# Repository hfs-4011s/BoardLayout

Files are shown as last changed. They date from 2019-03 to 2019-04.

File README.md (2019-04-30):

HFS 4011s PCB Design Files
=====
# Development Guide
### Software
PCB design software (EAGLE) can be downloaded [here](https://www.autodesk.com/education/free-software/eagle).

Tutorials:

[Schematic design tutorial](https://learn.sparkfun.com/tutorials/using-eagle-schematic/all)

[Creating device footprints](https://learn.sparkfun.com/tutorials/designing-pcbs-smd-footprints)

[Advanced layout](https://learn.sparkfun.com/tutorials/designing-pcbs-advanced-smd)

### Useful links
The ESP32 and USB design follows the same format as the
[HUZZAH32 ESP32 Feather](https://github.com/adafruit/Adafruit-HUZZAH32-ESP32-Feather-PCB),
so check out their [documentation](https://learn.adafruit.com/adafruit-huzzah32-esp32-feather/overview)
for programming the board using the Arduino IDE.

The battery charge design follows the same format as the [PowerBoost 500](https://github.com/adafruit/Adafruit-PowerBoost-500-Charger-PCB).
An overview can be found [here](https://learn.adafruit.com/adafruit-powerboost-500-plus-charger/overview).

# Usage
This board is meant to interface with an FPAA board developed at the Georgia
Institute of Technology and serves as part of an overall noise cancellation
pipeline meant to showcase the versatility of this technology. Our board handles
sending music and measured noise over to the FPAA, and the FPAA incorporates
our noise cancellation algorithm and sends its output to connected speakers.

This board, denoted as the HFS-4011s mainboard, includes circuitry for regulating
the battery supply voltage to 5V and 3.3V, handles charging the battery from a
micro-USB connector, and handles programming the onboard ESP32 via micro-USB.

The ESP32 is set up to connect to buttons for controlling the ANC state. A 5V
logic level SPI interface is set up and is meant to interface with LEDs to show
headphone status. The mainboard also contains a 16-bit DAC for converting the
received music to an analog signal to send over to an FPAA or speakers.

There are also a few onboard LEDs for debugging and status verification.

* `LED1` is green if the battery is fully charged
* `LED2` is orange if the battery is currently charging
* `PWR` is a power indicator LED and is blue if 5V is output from the regulator
* `LBO` is a battery status indicator LED and is red if the battery is discharged
* `D2` is a red LED connected to `GPIO13` meant for debugging

Even with solder paste, this board can be hard to assemble by hand. We ran into
a lot of problems regarding unintended shorts from the reflow process. If removing
the USB-UART bridge is necessary, the ESP32 can be programmed normally through
pins 34 and 35 (`u0RXD` and `u0TXD` respectively), but when you get to the
`Connecting...` stage, make sure the following protocol is followed:

* Short `GPIO2` and `GPIO0` to ground.
* Press the RESET button (`SW1`), which is connected to the ESP32 `EN` pin, to
momentarily reset the microcontroller. Pressing `SW1` shorts the `EN` pin to ground,
so this can be done manually as well.

After a couple of moments, the ESP32 should be flashed. The RESET button needs
to be pressed again to cycle the ESP32, and the flashed program should now run.

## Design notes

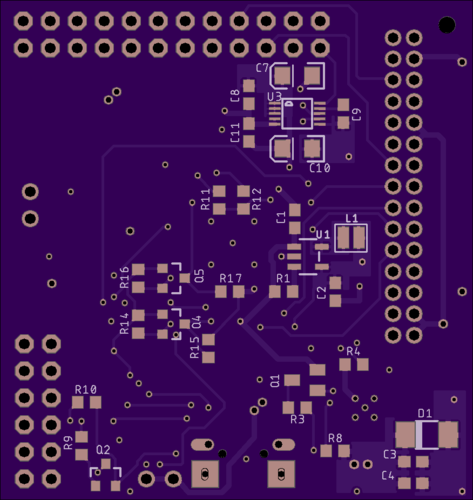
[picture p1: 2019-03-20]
HFS_4011s_Rev_0/osh_images/board_bottom.png

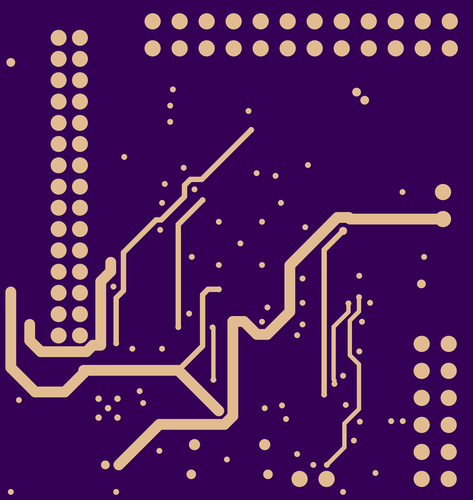
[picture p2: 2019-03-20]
HFS_4011s_Rev_0/osh_images/internal_signal_plane.png

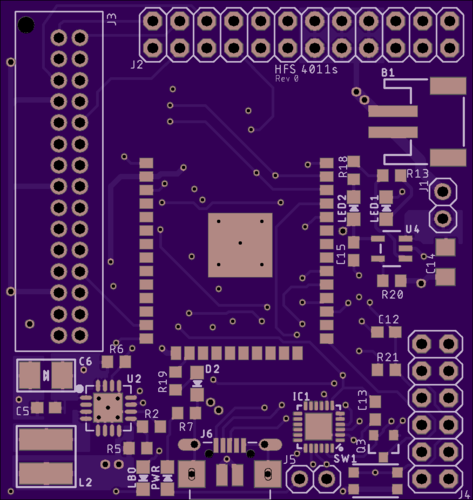
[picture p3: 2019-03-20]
HFS_4011s_Rev_0/osh_images/board_top.png

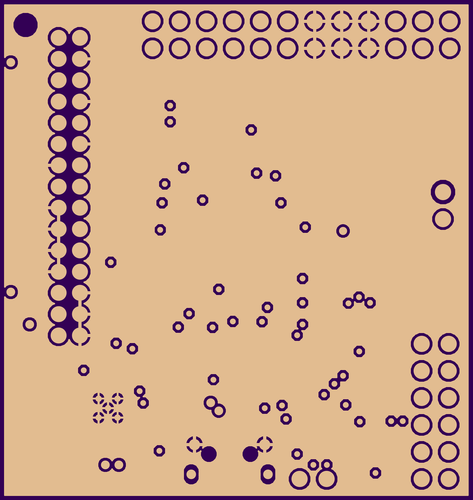
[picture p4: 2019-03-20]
HFS_4011s_Rev_0/osh_images/internal_ground_plane.png

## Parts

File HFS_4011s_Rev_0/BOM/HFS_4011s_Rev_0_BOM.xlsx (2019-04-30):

Official Number | Part | Value | Device | Package | Description | Quantity | Price 1 | Manufacturer_ID | Supplier_ID | Link 1 | Alternate ID | Alternate Link
1 | B1 | 3.7 V 6.6 Ah battery | BATTERY | JSTPH2 | CR1220 SMT - Digikey: 3001K-ND | 1 | 29.5 | 353 | 1528-1835-ND | https://www.digikey.com/product-detail/en/adafruit-industries-llc/353/1528-1835-ND/5054549 | 353 | https://www.adafruit.com/product/353
2 | C1, C3, C13, C15 | 10uF | C-EUC0603 | C0603 | CAPACITOR, European symbol | 4 | 0.21 | GRM188R61A106KE69D |  | https://www.digikey.com/product-detail/en/murata-electronics-north-america/GRM188R61A106KE69D/490-10474-1-ND/5026392 | JMK107BJ106MA-T | https://www.digikey.com/product-detail/en/taiyo-yuden/JMK107BJ106MA-T/587-1256-1-ND/931033
3 | C12 | 1uF | C-EUC0603 | C0603 | CAPACITOR, European symbol | 1 | 0.1 | CL10A105KP8NNNC |  | https://www.digikey.com/product-detail/en/samsung-electro-mechanics/CL10A105KP8NNNC/1276-1182-1-ND/3889268 | CL10A105KQ8NNNC | https://www.digikey.com/product-detail/en/samsung-electro-mechanics/CL10A105KQ8NNNC/1276-1036-1-ND/3889122
4 | C14 | 4.7uF | C-USC1206 | C1206 | CAPACITOR, American symbol | 1 | 0.26 | CL31B475KAHNNWE |  | https://www.digikey.com/product-detail/en/samsung-electro-mechanics/CL31B475KAHNNWE/1276-3178-1-ND/3891264 | CL31A475KOHNNNE | https://www.digikey.com/product-detail/en/samsung-electro-mechanics/CL31A475KOHNNNE/1276-3059-1-ND/3891145
5 | C2 | 22uF | C-EUC0603 | C0603 | CAPACITOR, European symbol | 1 | 0.31 | GRM188R61A226ME15D |  | https://www.digikey.com/product-detail/en/murata-electronics-north-america/GRM188R61A226ME15D/490-10476-1-ND/5026394 | CL10A226MQ8NRNE | https://www.digikey.com/product-detail/en/samsung-electro-mechanics/CL10A226MQ8NRNE/1276-2868-1-ND/3890954
6 | C4, C8, C11 | 0.1uF | C-EUC0603 | C0603 | CAPACITOR, European symbol | 3 | 0.1 | CL10B104KB8NNNC |  | https://www.digikey.com/product-detail/en/samsung-electro-mechanics/CL10B104KB8NNNC/1276-1000-1-ND/3889086 | CL10B104KO8NNNC | https://www.digikey.com/product-detail/en/samsung-electro-mechanics/CL10B104KO8NNNC/1276-1005-1-ND/3889091
7 | C5 | 2.2uF | C-EUC0603 | C0603 | CAPACITOR, European symbol | 1 | 0.11 | CL10A225KP8NNNC |  | https://www.digikey.com/product-detail/en/samsung-electro-mechanics/CL10A225KP8NNNC/1276-1085-1-ND/3889171 | CL10A225KQ8NNNC | https://www.digikey.com/product-detail/en/samsung-electro-mechanics/CL10A225KQ8NNNC/1276-1183-1-ND/3889269
8 | C6 | 100uF/6V | CAP_TANTALUMB/3528_REFLOW | EIA3528-21/B-R | Tantalum Capacitors | 1 | 0.65 | TPSB107K006R0250 |  | https://www.digikey.com/product-detail/en/avx-corporation/TPSB107K006R0250/478-3080-6-ND/1642660 | TPSB107M006R0250 | https://www.digikey.com/product-detail/en/avx-corporation/TPSB107M006R0250/478-4978-6-ND/1888274
9 | C7, C10 | 10uF | 10UF-TANT | EIA3216 | 10uF Tantalum SMT | 2 | 0.41 | TPSA106K010R0900 |  | https://www.digikey.com/product-detail/en/avx-corporation/TPSA106K010R0900/478-1751-1-ND/564783 | TPSA106M010R0900 | https://www.digikey.com/product-detail/en/avx-corporation/TPSA106M010R0900/478-9034-1-ND/4561900
10 | C9 | 10nF | C-EUC0603 | C0603 | CAPACITOR, European symbol | 1 | 0.1 | CL10B103KB8NNNC |  | https://www.digikey.com/product-detail/en/samsung-electro-mechanics/CL10B103KB8NNNC/1276-1009-1-ND/3889095 | CL10B103KB8NCNC | https://www.digikey.com/product-detail/en/samsung-electro-mechanics/CL10B103KB8NCNC/1276-1921-1-ND/3890007
11 | D1 | SMAJ5.0CALFDKR-ND | SMAJ5.0CALFDKR-ND | DO-214AC | TVS Diode | 1 | 0.47 | SMAJ5.0CA |  | https://www.digikey.com/product-detail/en/littelfuse-inc/SMAJ5.0CA/SMAJ5.0CALFCT-ND/762463 | SMAJ5.0CA | https://www.mouser.com/ProductDetail/Bourns/SMAJ50CA?qs=sGAEpiMZZMuGq%2Fv7cZsUqyrTMop0Zr6V
12 | D2, LBO | RED | LED0805_NOOUTLINE | CHIPLED_0805_NOOUTLINE | LED | 1 | 0.31 | LTST-C171KRKT |  | https://www.digikey.com/product-detail/en/lite-on-inc/LTST-C171KRKT/160-1427-1-ND/386800 | LTST-C170KRKT | https://www.digikey.com/product-detail/en/lite-on-inc/LTST-C170KRKT/160-1415-1-ND/386778
13 | IC1 | CP2104 | CP2104 | QFN24_4MM_SMSC | CP2104 - USB to UART Bridge | 1 | 1.65 | CP2104-F03-GMR |  | https://www.digikey.com/product-detail/en/silicon-labs/CP2104-F03-GMR/336-4146-1-ND/7650425 | CP2104-F03-GMR | https://www.mouser.com/ProductDetail/Silicon-Labs/CP2104-F03-GMR
42 | J1 | 1X02 | 1X02 | 1X02 | Power Switch and ANC Switch | 2 | 1.5 | EG1218 | COM-00102 | https://www.sparkfun.com/products/102 | EG1903-ND | https://www.digikey.com/product-detail/en/e-switch/EG1218/EG1903-ND/101726
40 | J2, J4, J5 | 2x23 Stacking Headers | 2x23 | 2x23 | 2 pack of 2x23 Stacking header pins | 1 | 4.95 | 706 |  | https://www.adafruit.com/product/706 | PRT-12790 | https://www.sparkfun.com/products/12790
14 |  |  | Molex_Socket_Contact |  | Socket contacts for iGrid connector (50 cost 7.18) Only really need to buy once/twice since we probably only need this for one/two boards | 10 | 0.192 | 5016471100 | WM13028-ND | https://www.digikey.com/product-detail/en/molex/5016471100/WM13028-ND/2818865 | 51R1306 | https://www.newark.com/molex/501647-1100/contact-socket-22awg-crimp/dp/51R1306?CMP=AFC-OP#
 |  |  |  |  | Molex iGrid mating connector | 1 | 2.37 | 501646-3000 |  | https://www.digikey.com/product-detail/en/molex/501646-3000/WM6068-ND/1787769 | 501646-3000 | https://www.mouser.com/ProductDetail/Molex/501646-3000
15 | J3 |  | MOLEX_IGRID_15X2CONNECTOR | MOLEX_IGRID15X2CONNECTOR |  | 1 | 2.54 | 501645-3020 |  | https://www.digikey.com/product-detail/en/molex/501645-3020/WM6082-ND/1787783 | 501645-3020 | https://www.mouser.com/ProductDetail/Molex/501645-3020?qs=AcmJtBVhzkToA%2FCFca6o%252BA%3D%3D
16 | J6 | microUSB | USBMICRO_20329 | 4UCONN_20329 | USB Connectors | 1 | 0.78 | 10103592-0001LF |  | https://www.digikey.com/product-detail/en/amphenol-icc-fci/10103592-0001LF/609-4048-1-ND/2350355 | 10103592-0001LF | https://www.mouser.com/ProductDetail/Amphenol-FCI/10103592-0001LF?qs=EnLMdcWnKABhRNh1n9QQyg%3D%3D
17 | L1 | 2.2uH/NRH2412T2R2MNGH | INDUCTORNRH2412T | INDUCTOR_TAIYOYUDEN_NRH2412T | Inductors | 1 | 0.23 | NRH2412T2R2MNGH | 587-3443-1-ND | https://www.digikey.com/product-detail/en/taiyo-yuden/NRH2412T2R2MNGH/587-3443-1-ND/4157783 | 55AC0812 | https://www.newark.com/taiyo-yuden/nrh2412t2r2mngh/inductor-wirewound-2-2uh-1a/dp/55AC0812?CMP=AFC-OP
18 | L2 | VLC5045-6.8uH | INDUCTORTDK_VLC5045 | INDUCTOR_5X5MM_TDK_VLC5045 | Inductors (schematic version is obsolete) | 1 | 0.48 | VLS5045EX-6R8M | 445-174855-1-ND | https://www.digikey.com/product-detail/en/tdk-corporation/VLS5045EX-6R8M/445-174855-1-ND/6560412 | 32AC9101 | https://www.newark.com/tdk/vls5045ex-6r8m/inductor-6-8uh-2-9a-20-wirewound/dp/32AC9101?CMP=AFC-OP
19 | LED1 | GREEN | LED0805_NOOUTLINE | CHIPLED_0805_NOOUTLINE | LED | 1 | 0.31 | LTST-C171KGKT |  | https://www.digikey.com/product-detail/en/lite-on-inc/LTST-C171KGKT/160-1426-1-ND/386798 | LTST-C171GKT | https://www.digikey.com/product-detail/en/lite-on-inc/LTST-C171GKT/160-1423-6-ND/1218382
20 | LED2 | ORANGE | LED0805_NOOUTLINE | CHIPLED_0805_NOOUTLINE | LED | 1 | 0.31 | LTST-C170KFKT |  | https://www.digikey.com/product-detail/en/lite-on-inc/LTST-C170KFKT/160-1413-1-ND/386774 | LTST-C171AKT | https://www.digikey.com/product-detail/en/lite-on-inc/LTST-C171AKT/160-1419-1-ND/386784
21 | PWR | BLUE | LED0805_NOOUTLINE | CHIPLED_0805_NOOUTLINE | LED | 1 | 0.51 | LTST-C171TBKT |  | https://www.digikey.com/product-detail/en/lite-on-inc/LTST-C171TBKT/160-1645-1-ND/573585 | LTST-C170TBKT | https://www.digikey.com/product-detail/en/lite-on-inc/LTST-C170TBKT/160-1579-1-ND/564889
22 | Q1 | MMUN2133LT1G | MUN2114T1-PNP_DRIVER-SC59-BEC | SC59-BEC | PNP Bias Resistor Transistor | 1 | 0.13 | MMUN2133LT1G |  | https://www.digikey.com/product-detail/en/on-semiconductor/MMUN2133LT1G/MMUN2133LT1GOSCT-ND/2705149 | MMUN2133LT1G | https://www.mouser.com/ProductDetail/ON-Semiconductor/MMUN2133LT1G
23 | Q2, Q3 | mmbt2222 | TRANSISTOR_NPNSOT23-3 | SOT23-3 | Transistor NPN | 2 | 0.13 | MMBT2222LT1G |  | https://www.digikey.com/product-detail/en/on-semiconductor/MMBT2222LT1G/MMBT2222LT1GOSCT-ND/1139808 | MMBT2222A-TP | https://www.digikey.com/product-detail/en/micro-commercial-co/MMBT2222A-TP/MMBT2222ATPMSCT-ND/717394
24 | Q4, Q5 | BSS138 | MOSFET-NCHANNELSMD | SOT23-3 | N-channel MOSFET | 2 | 0.31 | BSS138 |  | https://www.digikey.com/product-detail/en/on-semiconductor/BSS138/BSS138CT-ND/244294 | BSS138 | https://www.mouser.com/ProductDetail/ON-Semiconductor-Fairchild/BSS138
 | R1 | 100K | R-US_R0603 | R0603 | RESISTOR, American symbol | 1 | 0.11 | RR0816P-104-D |  | https://www.digikey.com/product-detail/en/susumu/RR0816P-104-D/RR08P100KDCT-ND/432772 | ERA-3AEB104V | https://www.digikey.com/product-detail/en/panasonic-electronic-components/ERA-3AEB104V/P100KDBCT-ND/1466100
 | R11, R12 | 5k | R-US_R0603 | R0603 | RESISTOR, American symbol (bought 4.99kohm resistors) | 2 | 0.35 | ERA-3AEB4991V |  | https://www.digikey.com/product-detail/en/panasonic-electronic-components/ERA-3AEB4991V/P4.99KDBCT-ND/3075985 | ERA-3AEB4991V | https://www.mouser.com/ProductDetail/Panasonic/ERA-3AEB4991V
25 | R14, R15, R16, R17 | 5.1k | R-US_R0603 | R0603 | RESISTOR, American symbol | 4 | 0.35 | ERA-3AEB512V |  | https://www.digikey.com/product-detail/en/panasonic-electronic-components/ERA-3AEB512V/P5.1KDBCT-ND/1466069 | RG1608N-512-W-T1 | https://www.digikey.com/product-detail/en/susumu/RG1608N-512-W-T1/RG16N5.1KWCT-ND/600802
26 | R18 | 470 | R-US_R0603 | R0603 | RESISTOR, American symbol | 1 | 0.1 | CRGCQ0603J470R |  | https://www.digikey.com/product-detail/en/te-connectivity-passive-product/CRGCQ0603J470R/A130089CT-ND/8577921 | ERJ-3EKF4700V | https://www.digikey.com/product-detail/en/panasonic-electronic-components/ERJ-3EKF4700V/P470HCT-ND/1746781
27 | R2, R8 | 340K | R-US_R0603 | R0603 | RESISTOR, American symbol | 2 | 0.8 | RN73C1J340KBTD |  | https://www.digikey.com/product-detail/en/te-connectivity-passive-product/RN73C1J340KBTD/A124740CT-ND/6557785 | RC0603FR-07340KL | https://www.digikey.com/product-detail/en/yageo/RC0603FR-07340KL/311-340KHRCT-ND/730118
28 | R20 | 2k | R-US_R0603 | R0603 | RESISTOR, American symbol | 1 | 0.35 | ERA-3AEB202V |  | https://www.digikey.com/product-detail/en/panasonic-electronic-components/ERA-3AEB202V/P2.0KDBCT-ND/1466059 | RG1608P-202-B-T5 | https://www.digikey.com/product-detail/en/susumu/RG1608P-202-B-T5/RG16P2.0KBCT-ND/1240891
29 | R3, R7, R13, R19 | 1K | R-US_R0603 | R0603 | RESISTOR, American symbol | 4 | 0.1 | ESR03EZPJ102 |  | https://www.digikey.com/product-detail/en/rohm-semiconductor/ESR03EZPJ102/RHM1.0KDCT-ND/1762924 | ESR03EZPF1001 | https://www.digikey.com/product-detail/en/rohm-semiconductor/ESR03EZPF1001/RHM1.00KADCT-ND/1983752
30 | R4 | 200K | R-US_R0603 | R0603 | RESISTOR, American symbol | 1 | 0.35 | ERA-3AEB204V | P200KDBCT-ND | https://www.digikey.com/product-detail/en/panasonic-electronic-components/ERA-3AEB204V/P200KDBCT-ND/1466107 | KTR03EZPF2003 | https://www.digikey.com/product-detail/en/rohm-semiconductor/KTR03EZPF2003/RHM200KAYCT-ND/4054128
31 | R5, R6 | 1.87Mohm | R-US_R0603 | R0603 | RESISTOR, American symbol | 2 | 0.1 | RMCF0603FT1M87 | RMCF0603FT1M87CT-ND | https://www.digikey.com/product-detail/en/stackpole-electronics-inc/RMCF0603FT1M87/RMCF0603FT1M87CT-ND/7790193 | KTR18EZPF1874 | https://www.digikey.com/product-detail/en/rohm-semiconductor/KTR18EZPF1874/RHM1.87MAIDKR-ND/4057416
32 | R9, R10, R21 | 10k | R-US_R0603 | R0603 | RESISTOR, American symbol | 3 | 0.1 | RNCP0603FTD10K0 |  | https://www.digikey.com/product-detail/en/stackpole-electronics-inc/RNCP0603FTD10K0/RNCP0603FTD10K0CT-ND/2240478 | RR0816P-103-D | https://www.digikey.com/product-detail/en/susumu/RR0816P-103-D/RR08P10.0KDCT-ND/432748
33 | SW1 | KMR2 | SWITCH_TACT_SMT4.6X2.8 | BTN_KMR2_4.6X2.8 | SMT Tact Switches | 1 | 0.52 | KMR231NG LFS | CKN10246CT-ND | https://www.digikey.com/product-detail/en/c-k/KMR231NG-LFS/CKN10246CT-ND/2176497 | KMR231NGLFS | https://www.mouser.com/ProductDetail/CK/KMR231NGLFS?qs=sGAEpiMZZMtn8lxF5bBjIfqHKXOiRuhv
34 | U1 | LM3671MF-3.3/NOPB | VREG_LM3671 | SOT23-5 | LM3671 - 600mA DC-DC Step-Down Converter | 1 | 1.43 | LM3671MF-3.3/NOPB | LM3671MF-3.3/NOPBCT-ND | https://www.digikey.com/product-detail/en/LM3671MF-3.3-NOPB/LM3671MF-3.3-NOPBCT-ND/1590190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 | LM3671MF-3.3/NOPB | https://www.ti.com/store/ti/en/p/product/?p=LM3671MF-3.3/NOPB
35 | U2 | TPS61090RSAR | VREG_TPS6103X | PVQFN-16 | TPS6103x 4A Boost - 1.8-5.5V Input, Adjustable Output to 5.5V | 1 | 2.41 | TPS61090RSAR | 296-15259-1-ND | https://www.digikey.com/product-detail/en/texas-instruments/TPS61090RSAR/296-15259-1-ND/566899 | TPS61090RSARG4 | https://www.ti.com/store/ti/en/p/product/?p=TPS61090RSAR
36 | U3 | AD5693R | AD5693R | MSOP10 | 16 Bit Digital to Analog Converter 1 10-MSOP | 1 | 7.76 | AD5693RBRMZ (https://octopart.com/ad5693rbrmz-analog+devices-38924305?r=sp&s=v_hnMM3ST5uJPWV0O7eAkA) | AD5693RARMZ-ND | https://www.digikey.com/product-detail/en/analog-devices-inc/AD5693RARMZ/AD5693RARMZ-ND/4806815 | 584-AD5693RARMZ | https://www.mouser.com/Search/Refine?N=4290538360&Keyword=584-AD5693RARMZ
37 | U4 | MCP73831T-2ACI/OT | MCP73831/2 | SOT23-5 | MCP73831/2 LIPO Charger | 1 | 0.57 | MCP73831T-2ACI/OT | 579-MCP73831T-2ACIOT | https://www.digikey.com/product-detail/en/MCP73831T-2ACI-OT/MCP73831T-2ACI-OTCT-ND/1979802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 | MCP73831T-2ACI/OTCT-ND | https://www.mouser.com/ProductDetail/Microchip-Technology/MCP73831T-2ACI-OT
38 | X1 | ESP32_WROOM32_SKINNY | ESP32_WROOM32_SKINNY | WROOM32_SKINNY |  | 1 | 3.8 | ESP32_WROOM32_SKINNY | 1904-1010-1-ND | https://www.digikey.com/product-detail/en/ESP32-WROOM-32/1904-1010-1-ND/8544305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 | 356-ESP-WROOM-32 | https://www.mouser.com/ProductDetail/Espressif-Systems/ESP32-WROOM-32
39 |  |  |  |  | ESD Bag to hold our board | 1 | 0.11 | 30035 | SCP417-ND | https://www.digikey.com/product-detail/en/scs/30035/SCP417-ND/3430456 | 13605 | https://www.digikey.com/product-detail/en/desco/13605/16-1032-ND/299792
40 |  | n/a | n/a | n/a | 10 pack of 1x36 header pins Only buy once | 1 | 4.95 | 3009 | n/a | https://www.adafruit.com/product/3009 | 392 | https://www.adafruit.com/product/392
 |  |  | Microphones |  |  | 2 | 6.95 | BOB-12758 | 1568-1472-ND | https://www.digikey.com/product-detail/en/sparkfun-electronics/BOB-12758/1568-1472-ND/6592307 |  | https://www.sparkfun.com/products/12758
43 |  | n/a | Pushbuttons | n/a | Momentary Pushbutton Switch - 12mm Square | 2 | 0.35 | COM-00097 |  | https://www.sparkfun.com/products/97 | COM-09190 | https://www.sparkfun.com/products/9190
44 |  | n/a | Audio Amplifiers | n/a | Mono Audio Amp Breakout | 2 | 7.95 | TPA2005D1 |  | https://www.sparkfun.com/products/11044 | 2130 | https://www.adafruit.com/product/2130
 |  |  | Speakers |  |  | 2 | 2.55 | CE38MB-32 |  | https://www.parts-express.com/dayton-audio-ce-series-ce38mb-32-1-1-2-mini-speaker-black-32-ohm--285-131 | COM-09151 | https://www.sparkfun.com/products/9151
 |  |  |  |  |  | Totals | 116.49

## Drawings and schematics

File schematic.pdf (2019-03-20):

# CP2104 GND

# 2k GND

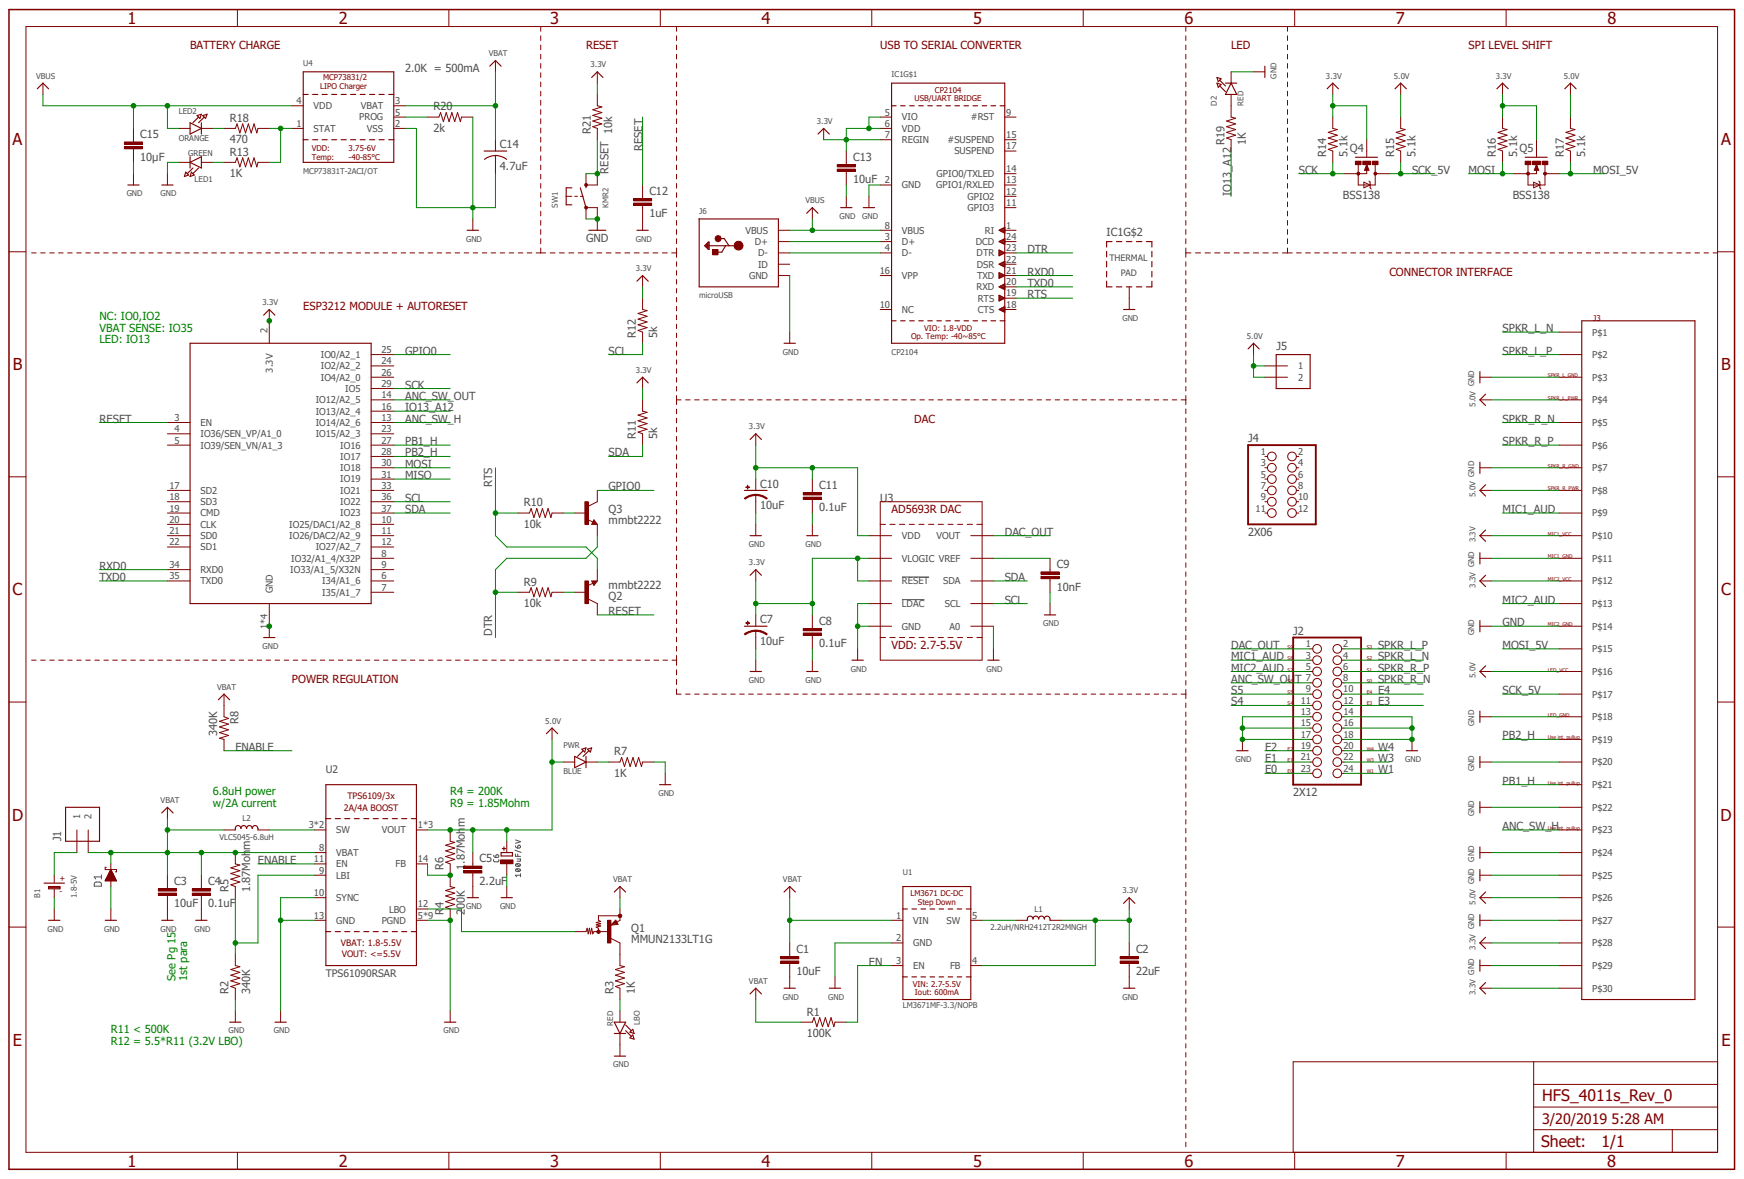
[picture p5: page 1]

GND
LED: IO13 See Pg 15 1st para

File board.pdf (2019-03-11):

L1 | B1 PWR R2 | R5 Q3 | J3 U³

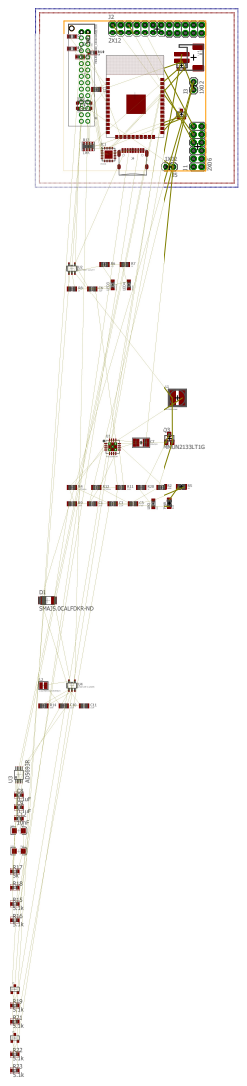
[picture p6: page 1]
J5 mmbt2222 mmbt2222; 2X06 VLC5045-6.8uH; 1.8⁻5V BLUE; 1K MMUN2133LT1G¹X02

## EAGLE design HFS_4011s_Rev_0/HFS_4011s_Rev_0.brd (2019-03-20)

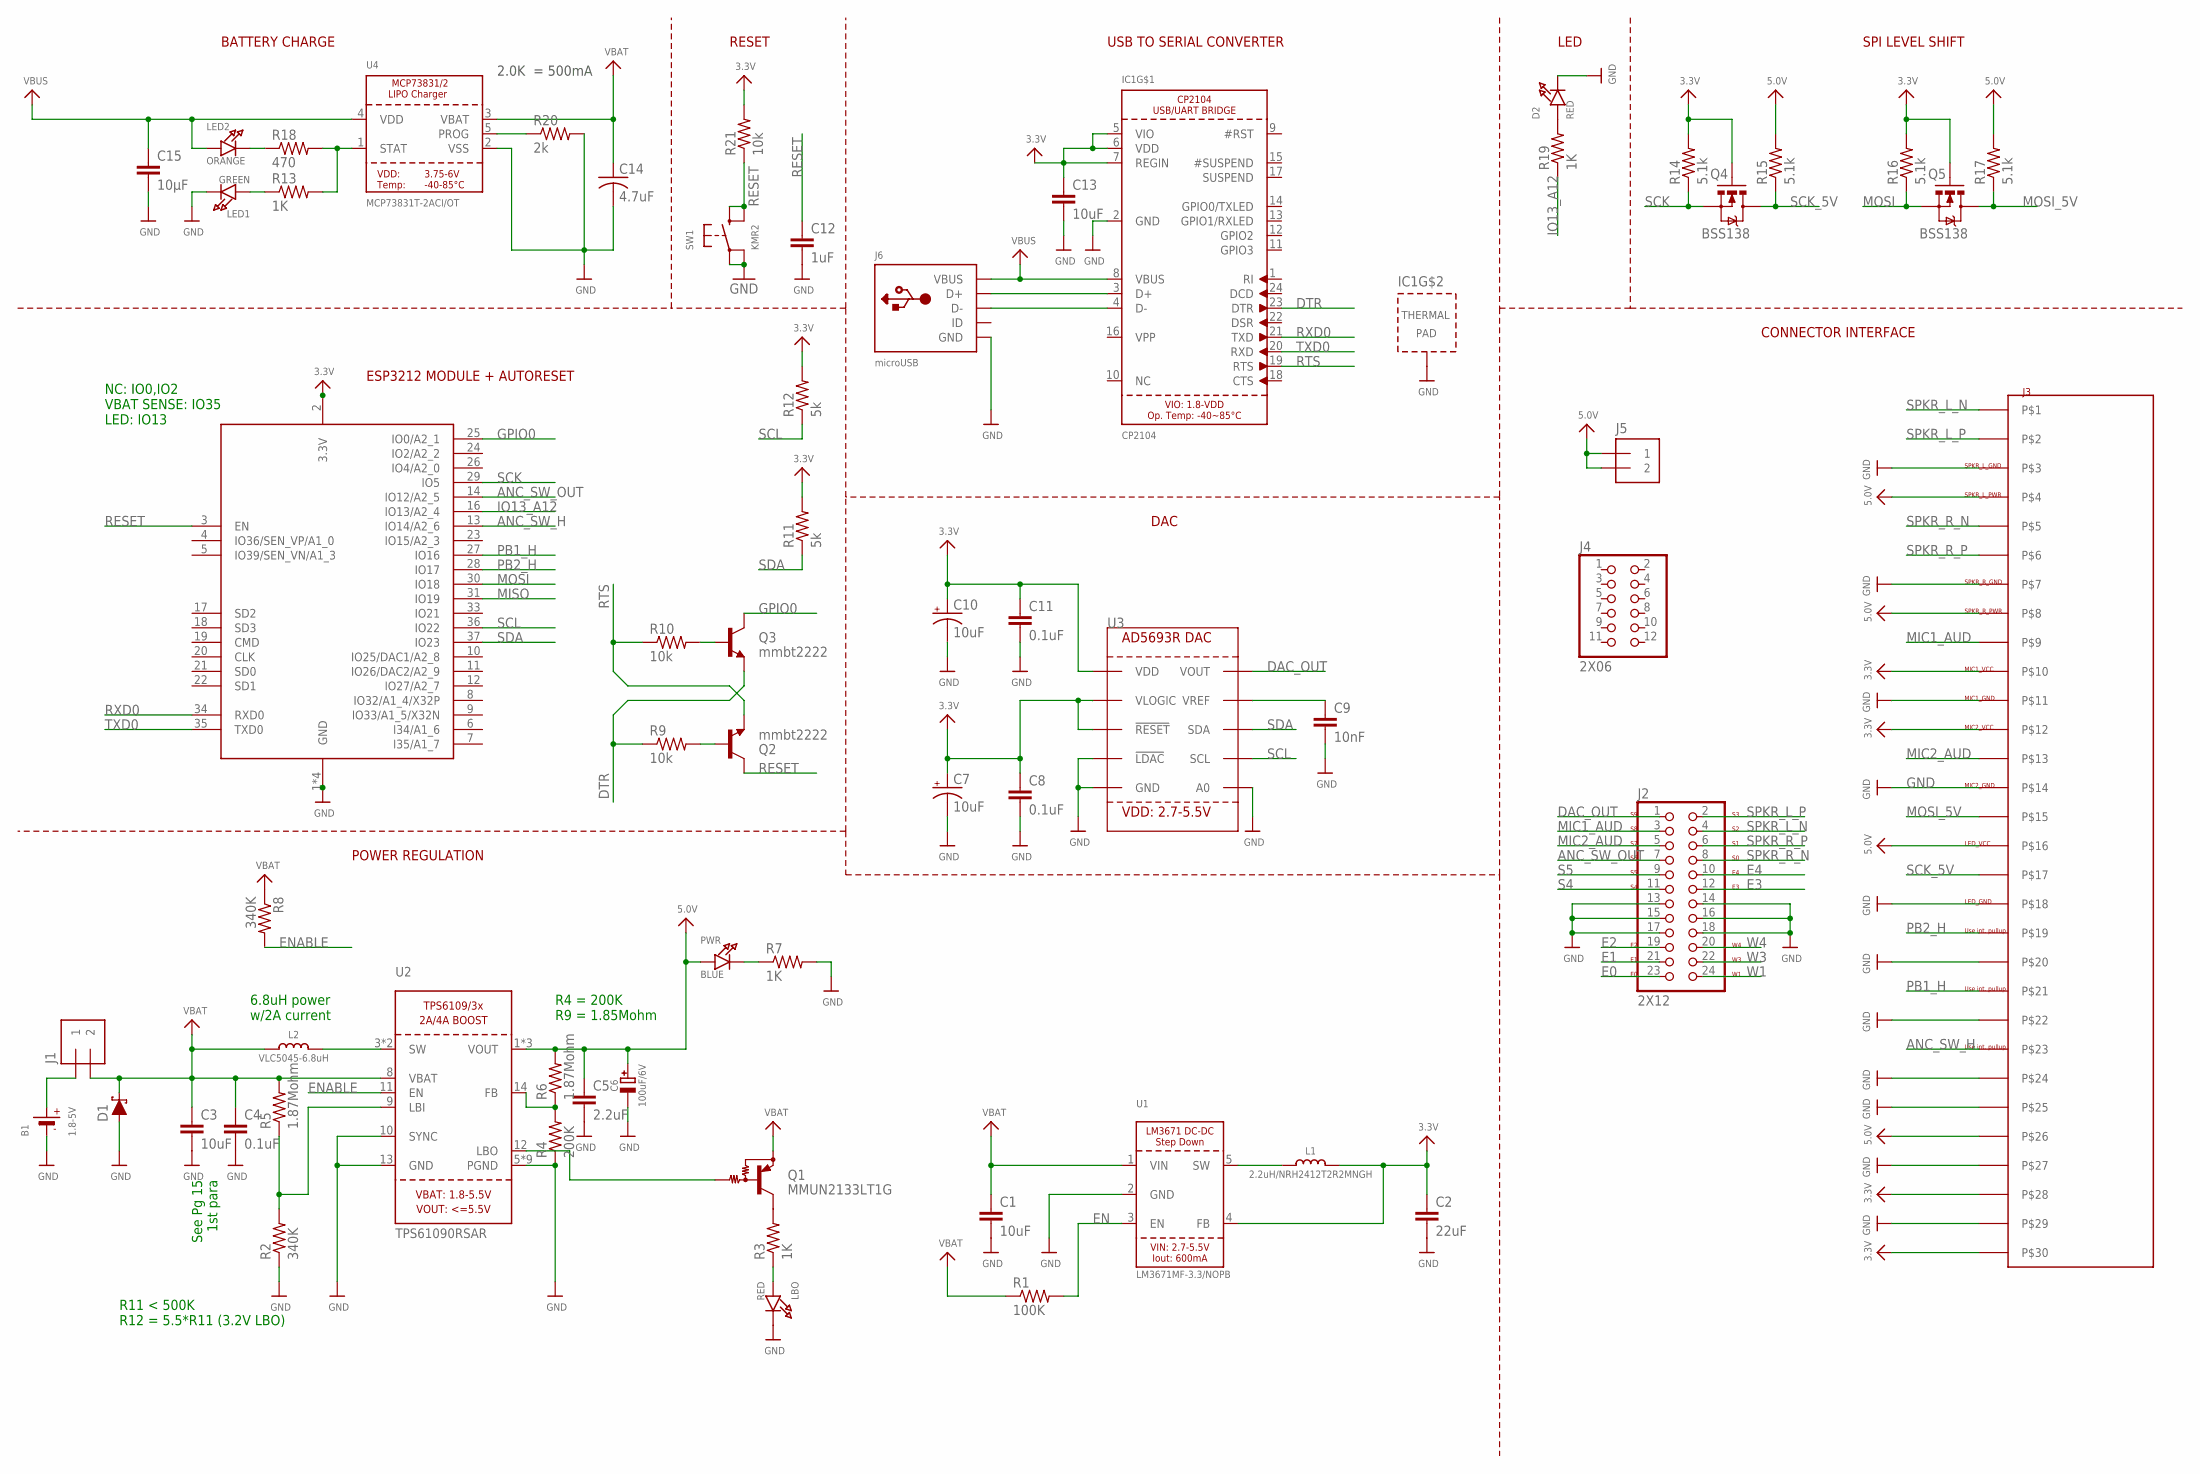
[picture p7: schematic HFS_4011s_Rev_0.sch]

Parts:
B1: 1.8-5V; JSTPH2
C1, C3, C13: 10uF; C0603
C2: 22uF; C0603
C4, C8, C11: 0.1uF; C0603
C5: 2.2uF; C0603
C6: 100uF/6V; EIA3528-21/B-R
C7, C10: 10uF; EIA3216
C9: 10nF; C0603
C12: 1uF; C0603
C14: 4.7uF; C1206
C15: 10µF; C0603
D1: SMAJ5.0CALFDKR-ND; DO-214AC
D2: RED; CHIPLED_0805_NOOUTLINE
IC1: CP2104; QFN24_4MM_SMSC
J1, J5: 1X02
J2: 2X12
J3: MOLEX_IGRID_15X2CONNECTOR; MOLEX_IGRID15X2CONNECTOR
J4: 2X06
J6: microUSB; 4UCONN_20329
L1: 2.2uH/NRH2412T2R2MNGH; INDUCTOR_TAIYOYUDEN_NRH2412T
L2: VLC5045-6.8uH; INDUCTOR_5X5MM_TDK_VLC5045
LBO: RED; CHIPLED_0805_NOOUTLINE
LED1: GREEN; CHIPLED_0805_NOOUTLINE
LED2: ORANGE; CHIPLED_0805_NOOUTLINE
PWR: BLUE; CHIPLED_0805_NOOUTLINE
Q1: MMUN2133LT1G; SC59-BEC
Q2, Q3: mmbt2222; SOT23-3
Q4, Q5: BSS138; SOT23-3
R1: 100K; R0603
R2, R8: 340K; R0603
R3, R7, R13, R19: 1K; R0603
R4: 200K; R0603
R5, R6: 1.87Mohm; R0603
R9, R10, R21: 10k; R0603
R11, R12: 5k; R0603
R14, R15, R16, R17: 5.1k; R0603
R18: 470; R0603
R20: 2k; R0603
SW1: KMR2; BTN_KMR2_4.6X2.8
U1: LM3671MF-3.3/NOPB; SOT23-5
U2: TPS61090RSAR; PVQFN-16
U3: AD5693R; MSOP10
U4: MCP73831T-2ACI/OT; SOT23-5
X1: ESP32_WROOM32_SKINNY; WROOM32_SKINNY

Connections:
3.3V: C2.1, C7.A (+), C8.1, C10.A (+), C11.1, C13.1, IC1.5 (VIO), IC1.6 (VDD), IC1.7 (REGIN), J3.P$10, J3.P$12, J3.P$28, J3.P$30, L1.2, Q4.1 (G), Q5.1 (G), R11.2, R12.2, R14.2, R16.2, R21.2, U1.4 (FB), U3.1 (VDD), U3.2 (VLOGIC), U3.3 (!RESET!), X1.2 (3.3V)
5.0V: C5.1, C6.+, J3.P$4, J3.P$8, J3.P$16, J3.P$26, J5.1, J5.2, PWR.A, R6.2, R15.2, R17.2, U2.1 (VOUT), U2.15 (VOUT), U2.16 (VOUT)
ANC_SW_H: J3.P$23, X1.13 (IO14/A2_6)
ANC_SW_OUT: J2.7, X1.14 (IO12/A2_5)
DAC_OUT: J2.1, U3.10 (VOUT)
DTR: IC1.23 (DTR), Q3.2 (E), R9.1
E0: J2.23
E1: J2.21
E2: J2.19
E3: J2.12
E4: J2.10
EN: R1.2, U1.3 (EN)
ENABLE: R8.2, U2.11 (EN)
GND: B1.1 (-), C1.2, C2.2, C3.2, C4.2, C5.2, C6.-, C7.C (-), C8.2, C9.2, C10.C (-), C11.2, C12.2, C13.2, C14.2, C15.2, D1.A, D2.C, IC1.2 (GND), IC1.THERM (TP), J2.13, J2.14, J2.15, J2.16, J2.17, J2.18, J3.P$3, J3.P$7, J3.P$11, J3.P$14, J3.P$18, J3.P$20, J3.P$22, J3.P$24, J3.P$25, J3.P$27, J3.P$29, J6.BASE@1 (GND), J6.BASE@2 (GND), J6.GND, J6.SPRT@1 (GND), J6.SPRT@2 (GND), J6.SPRT@3 (GND), J6.SPRT@4 (GND), LBO.C, LED1.C, R2.1, R4.1, R7.2, R20.2, SW1.A, SW1.A' (P1), U1.2 (GND), U2.5 (PGND), U2.6 (PGND), U2.7 (PGND), U2.10 (SYNC), U2.13 (GND), U2.P$18 (PGND), U2.P$19 (PGND), U2.P$20 (PGND), U2.P$21 (PGND), U2.P$22 (PGND), U2.THERMAL (PGND), U3.4 (!LDAC!), U3.5 (GND), U3.6 (A0), U4.2 (VSS), X1.1 (GND), X1.15 (GND), X1.38 (GND), X1.P$1 (GND)
GPIO0: Q3.3 (C), X1.25 (IO0/A2_1)
IO13_A12: R19.1, X1.16 (IO13/A2_4)
LBO: Q1.B, U2.12 (LBO)
MIC1_AUD: J2.3, J3.P$9
MIC2_AUD: J2.5, J3.P$13
MISO: X1.31 (IO19)
MOSI: Q5.2 (S), R16.1, X1.30 (IO18)
MOSI_5V: J3.P$15, Q5.3 (D), R17.1
unnamed: LED2.C, R18.1
unnamed: IC1.3 (D+), J6.D+
unnamed: L2.P$2 (2), U2.3 (SW), U2.4 (SW)
unnamed: R2.2, R5.1, U2.9 (LBI)
unnamed: D2.A, R19.2
unnamed: IC1.4 (D-), J6.D-
unnamed: R13.2, R18.2, U4.1 (STAT)
unnamed: R20.1, U4.5 (PROG)
unnamed: LED1.A, R13.1
unnamed: PWR.C, R7.1
unnamed: R4.2, R6.1, U2.14 (FB)
unnamed: Q2.1 (B), R9.2
unnamed: Q3.1 (B), R10.2
unnamed: LBO.A, R3.1
unnamed: Q1.C, R3.2
unnamed: B1.2 (+), J1.1
unnamed: L1.1, U1.5 (SW)
unnamed: C9.1, U3.9 (VREF)
PB1_H: J3.P$21, X1.27 (IO16)
PB2_H: J3.P$19, X1.28 (IO17)
RESET: C12.1, Q2.3 (C), R21.1, SW1.B (S), SW1.B' (S1), X1.3 (EN)
RTS: IC1.19 (RTS), Q2.2 (E), R10.1
RXD0: IC1.21 (TXD), X1.34 (RXD0)
S4: J2.11
S5: J2.9
SCK: Q4.2 (S), R14.1, X1.29 (IO5)
SCK_5V: J3.P$17, Q4.3 (D), R15.1
SCL: R12.1, U3.7 (SCL), X1.36 (IO22)
SDA: R11.1, U3.8 (SDA), X1.37 (IO23)
SPKR_L_N: J2.4, J3.P$1
SPKR_L_P: J2.2, J3.P$2
SPKR_R_N: J2.8, J3.P$5
SPKR_R_P: J2.6, J3.P$6
TXD0: IC1.20 (RXD), X1.35 (TXD0)
VBAT: C1.1, C3.1, C4.1, C14.1, D1.C, J1.2, L2.P$1 (1), Q1.E, R1.1, R5.2, R8.1, U1.1 (VIN), U2.8 (VBAT), U4.3 (VBAT)
VBUS: C15.1, IC1.8 (VBUS), J6.VBUS, LED2.A, U4.4 (VDD)
W1: J2.24
W3: J2.22
W4: J2.20

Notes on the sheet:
RESET
USB TO SERIAL CONVERTER
LED
ESP3212 MODULE + AUTORESET
NC: IO0,IO2 VBAT SENSE: IO35 LED: IO13
2.0K = 500mA
See Pg 15 1st para
6.8uH power w/2A current
R11 < 500K R12 = 5.5*R11 (3.2V LBO)
R4 = 200K R9 = 1.85Mohm
BATTERY CHARGE
POWER REGULATION
DAC
LED_VCC
LED_GND
MIC1_VCC
MIC1_GND
MIC2_GND
MIC2_VCC
SPKR_L_PWR
SPKR_R_PWR
SPKR_R_GND
SPKR_L_GND
Use int. pullup
SPI LEVEL SHIFT
CONNECTOR INTERFACE

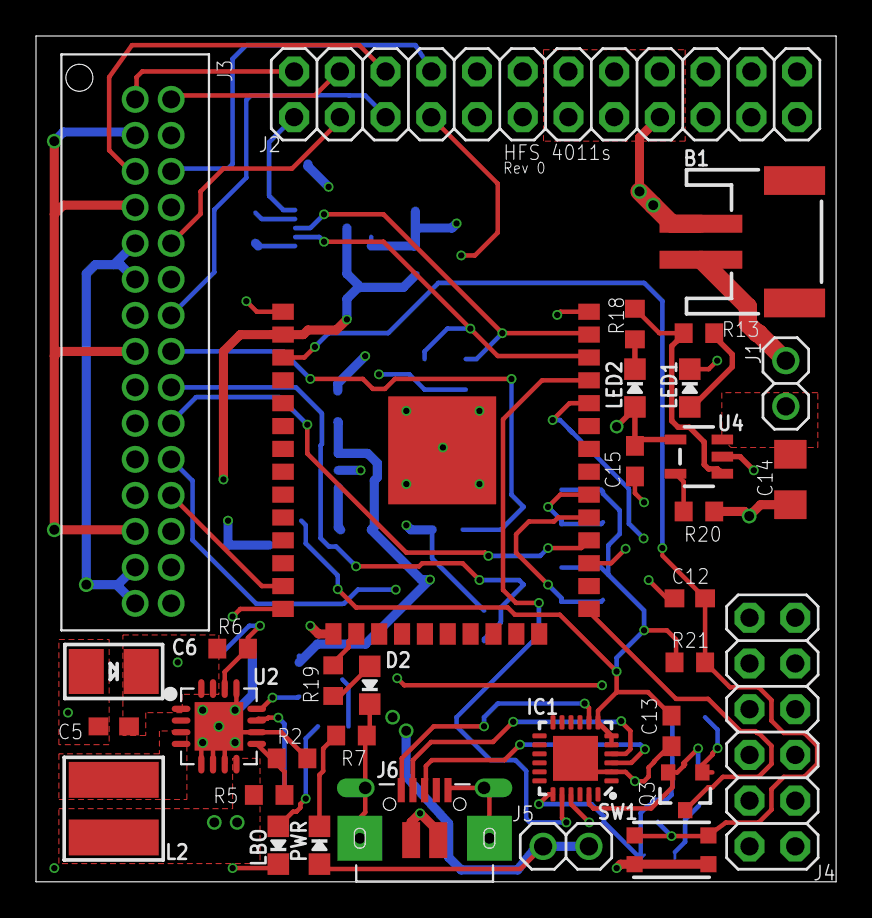
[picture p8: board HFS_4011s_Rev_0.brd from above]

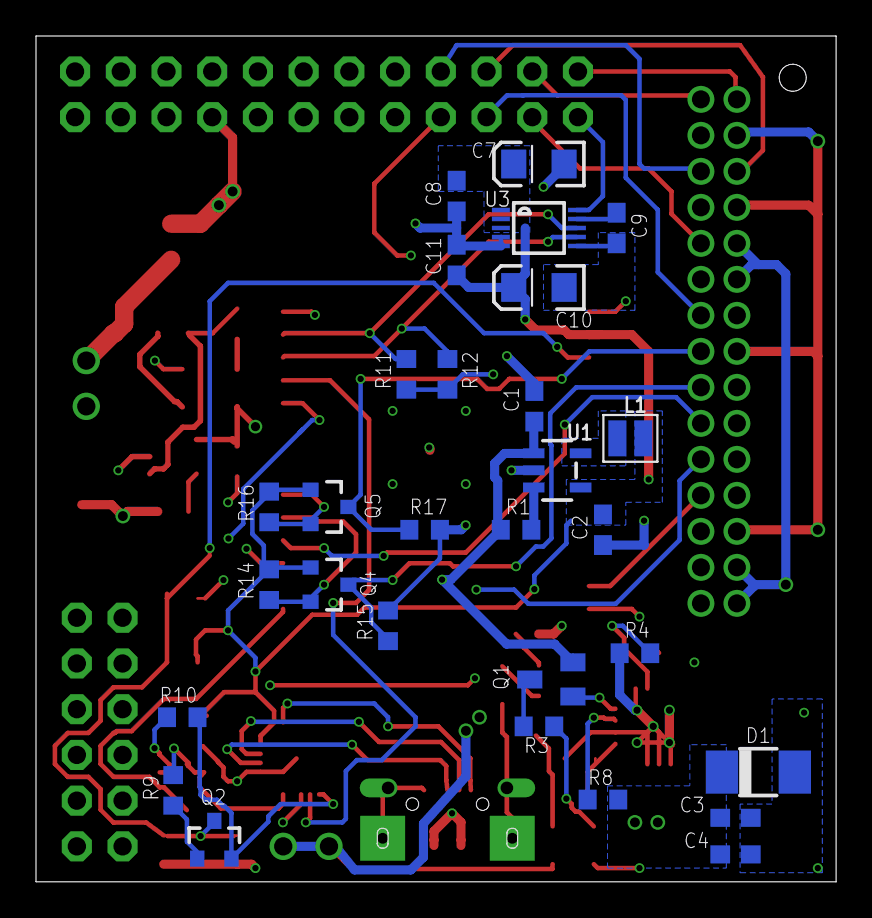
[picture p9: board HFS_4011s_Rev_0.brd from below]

Board: 4 copper layers, 44.5 x 47.0 mm, 63 parts (29 on the bottom side), 50 nets.

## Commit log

2019-02-08 First commit. Added readme with tutorials for board design.
2019-03-02 Started board design. Added necessary components for programming esp32, and added some useful libraries.
    [Adafruit HUZZAH32 ESP32 Feather.brd, Adafruit HUZZAH32 ESP32 Feather.sch, HFS_4011s_Rev_0.brd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]
2019-03-03 Added power circuitry to board. Using 5V buck boost and 3.3V LDO. Added 1x02 pin header for on-off switch.
    [Adafruit PowerBoost 500C.brd, Adafruit PowerBoost 500C.sch, HFS_4011s_Rev_0.brd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]
2019-03-03 Added TVS diode on battery, and moved switch to battery.
    [HFS_4011s_Rev_0.brd, HFS_4011s_Rev_0.sch]
2019-03-03 Cleaned up schematic and added ground planes.
    [HFS_4011s_Rev_0.brd, HFS_4011s_Rev_0.sch]
2019-03-04 Added in 3.3V buck converter and got rid of 3.3V LDO.
    [Adafruit LM3671 Buck.brd, Adafruit LM3671 Buck.sch, HFS_4011s_Rev_0.brd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]
2019-03-04 Created pdfs of board and schematic.
2019-03-10 Added in DAC
    [HFS_4011s_Rev_0.brd, HFS_4011s_Rev_0.sch, USB-C-Breakout.brd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]
2019-03-10 Added labels for FPAA IO. Still determining peripherals.
    [HFS_4011s_Rev_0.brd, HFS_4011s_Rev_0.sch]
2019-03-10 Working on IO. Need to get bigger connector for IO!
    [HFS_4011s_Rev_0.brd, HFS_4011s_Rev_0.sch]
2019-03-11 Addded peripherals. Still need to connect IO from microcontroller to connector.
    [HFS_4011s_Rev_0.brd, HFS_4011s_Rev_0.sch]
2019-03-11 Updated board and schematic pdfs.
2019-03-12 Started board layout. Placed battery charge circuitry, usb-serial conversion, and reset components onto board.
    [HFS_4011s_Rev_0.brd, HFS_4011s_Rev_0.sch]
2019-03-18 Changed usb C back to micro usb. Converted board to a 4-layer design. Routed 5V power supply.
    [HFS_4011s_Rev_0.brd, HFS_4011s_Rev_0.sch]
2019-03-18 Moved esp32 board up a little and added debug LED.
    [HFS_4011s_Rev_0.brd]
2019-03-19 All components on board. Need to finish routing some signals to connectors.
    [HFS_4011s_Rev_0.brd]
2019-03-19 Routed all components (0 airwire errors). But getting a lot of clearance errors. Also changed connector pinout
    [HFS_4011s_Rev_0.brd, HFS_4011s_Rev_0.sch]
2019-03-19 Renumbered components and fixing DRC errors.
    [HFS_4011s_Rev_0.brd, HFS_4011s_Rev_0.sch]
2019-03-20 Finished adding all silkscreen text. Got rid of some clearance errors. Seems like everything is set for fab.
    [HFS_4011s_Rev_0.brd, HFS_4011s_Rev_0.sch]
2019-03-20 Added board title text to silkscreen and added osh images to repo.
    [HFS_4011s_Rev_0.brd]
2019-03-25 Updated readme with links to adafruit boards for reference.
    [Adafruit HUZZAH32 ESP32 Feather.brd, Adafruit HUZZAH32 ESP32 Feather.sch, Adafruit LM3671 Buck.brd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]
2019-03-25 Adding gerbers to repo and working on BOM.
    [HFS_4011s_BOM.xlsx, HFS_4011s_Rev_0.csv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]
2019-04-30 Adding BOM used to order components.
    [HFS_4011s_BOM.xlsx, HFS_4011s_Rev_0.csv, HFS_4011s_Rev_0_BOM.xlsx]
2019-04-30 Wrote notes on how to use the board.

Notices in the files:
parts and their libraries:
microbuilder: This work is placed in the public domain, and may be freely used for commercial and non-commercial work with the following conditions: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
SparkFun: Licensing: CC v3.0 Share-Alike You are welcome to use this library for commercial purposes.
